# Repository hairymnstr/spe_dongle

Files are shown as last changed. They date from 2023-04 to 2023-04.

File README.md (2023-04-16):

# USB to Single Pair Ethernet Dongle

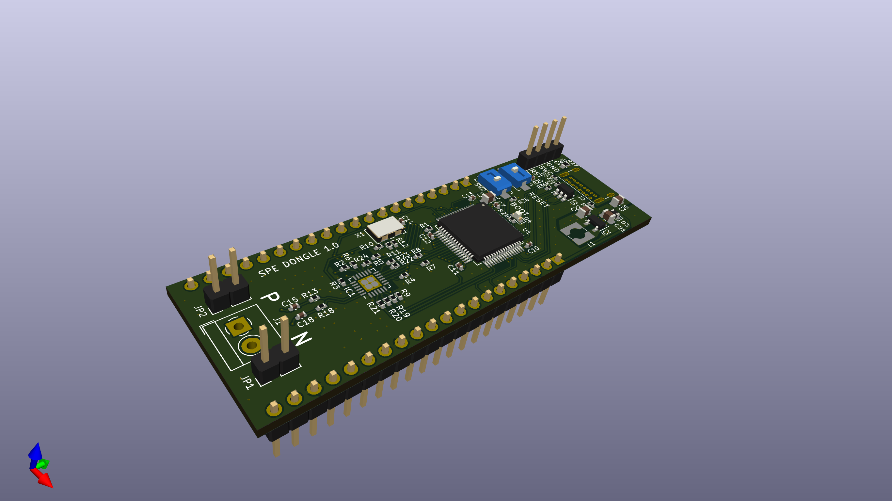
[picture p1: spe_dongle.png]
A screenshot of a CAD render of a small dev board with USB-C and screw terminal connectors


This project is a development board for experimenting with Single Pair Ethernet.
Specifically it has a 10Base-T1S PHY which means it can do short range 10Mbps
comms over a single twisted pair and it is capable of working in a multi-drop
bus without a networks switch.  The board has USB2.0 device only implementation
of the USB-C connector.  The first goal is to make a USB to SPE bridge so that
a Linux host can connect to an SPE network for testing with wireshark etc.

The board also has a number of GPIO broken out to aid in making up devices for
the bus or testing latencies by measuring GPIO toggling etc.

## Design decisions

1. **Why's it using such a low spec processor?**
It's the best I could find in stock.  Chip shortages.  I'd prefer to use
the STM32F407 perhaps, although the smallest pinout for that part is 100 pins
where I only need 64.

2. **Why don't you just buy the USB eval board from Microchip?**
You're right, there is a ready made USB eval board for the LAN867x, but it's
more expensive than this board even making small quantities AND I can't buy it
at the moment.

3. **Will it be the perfect solution then?**
No.  It's going to be okay for testing but the performance is probably going
to be poor.  Apart from anything else it's only Full Speed USB (12Mbps) which
has a 1kHz polling loop meaning you can get 1ms latency on transfers.  Probably
the best option for most applications would be an SPE enabled switch so you can
hook in a real network interface.  There are advantages to being directly connected
to the segment you're investigating for testing though.

## Project status

PCBs are on order.

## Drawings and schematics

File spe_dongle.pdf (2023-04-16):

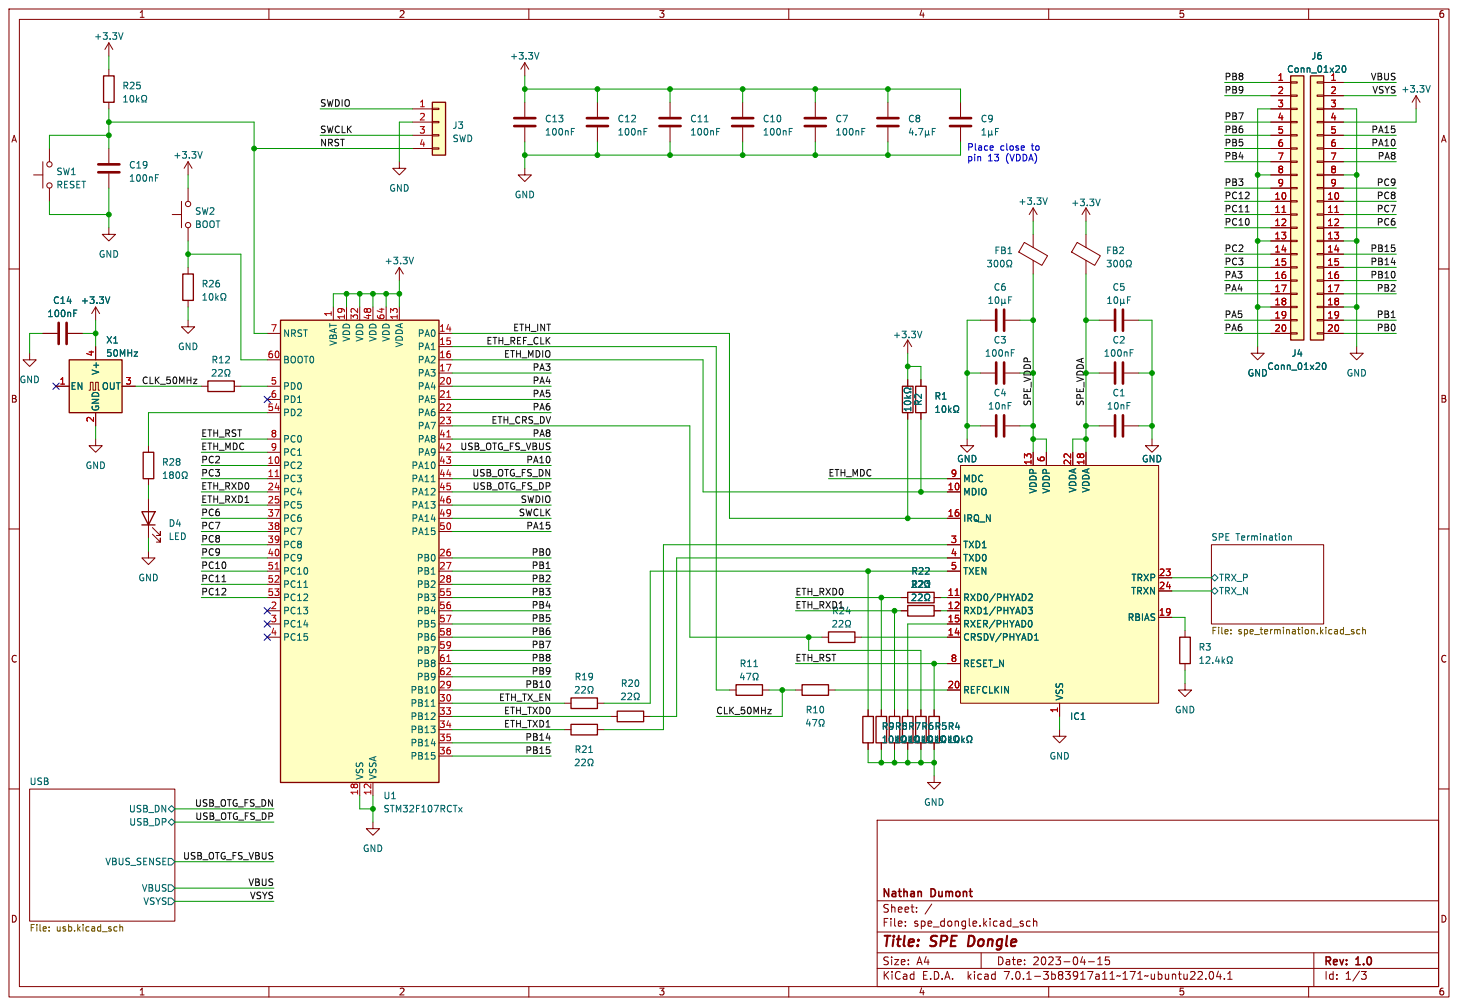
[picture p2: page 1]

1 PC2 10 PC3 11 VSSA 12 VDDA 13 PA0 14 PA1 15 PA2 16 PA3 17 VSS 18 VDD 19 PC13 2 PA4 20 PA5 21 PA6 22 PA7 23 PC4 24 PC5 25 PB0 26 PB1 27 PB2 28 PB10 29 PC14 3 PB11 30 VDD 32 PB12 33 PB13 34 PB14 35 PB15 36 PC6 37 PC7 38 PC8 39 PC15 4 PC9 40 PA8 41 PA9 42 PA10 43 PA11 44 PA12 45 PA13 46 VDD 48 PA14 49 PD0 5 PA15 50 PC10 51 PC11 52 PC12 53 PD2 54 PB3 55 PB4 56 PB5 57 PB6 58 PB7 59 PD1 6 BOOT0 60 PB8 61 PB9 62 VDD 64 NRST 7 PC0 8 PC1 9 U1STM32F107RCTx

1 MDIO 10 RXD0/PHYAD2 11 RXD1/PHYAD3 12 VDDP 13 CRSDV/PHYAD1 14 RXER/PHYAD0 15

Id: 1/3 Title: SPE Dongle

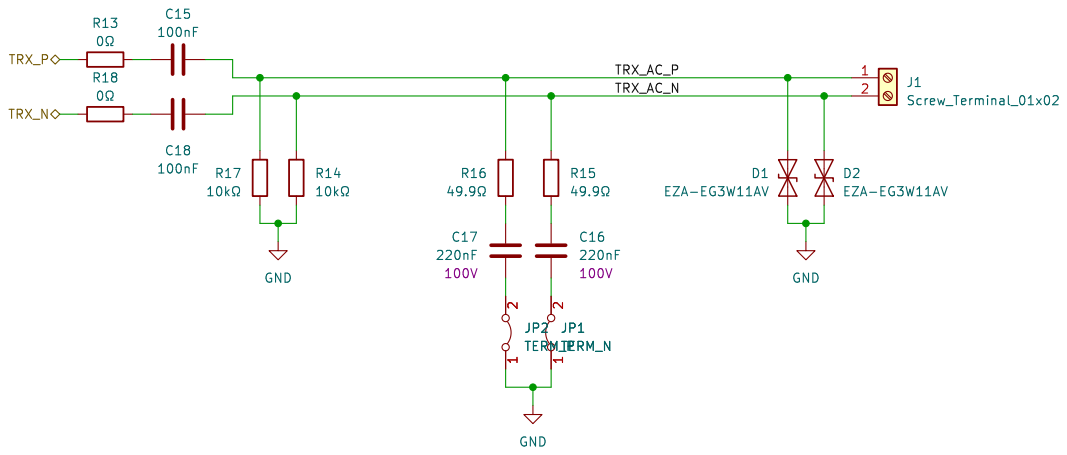
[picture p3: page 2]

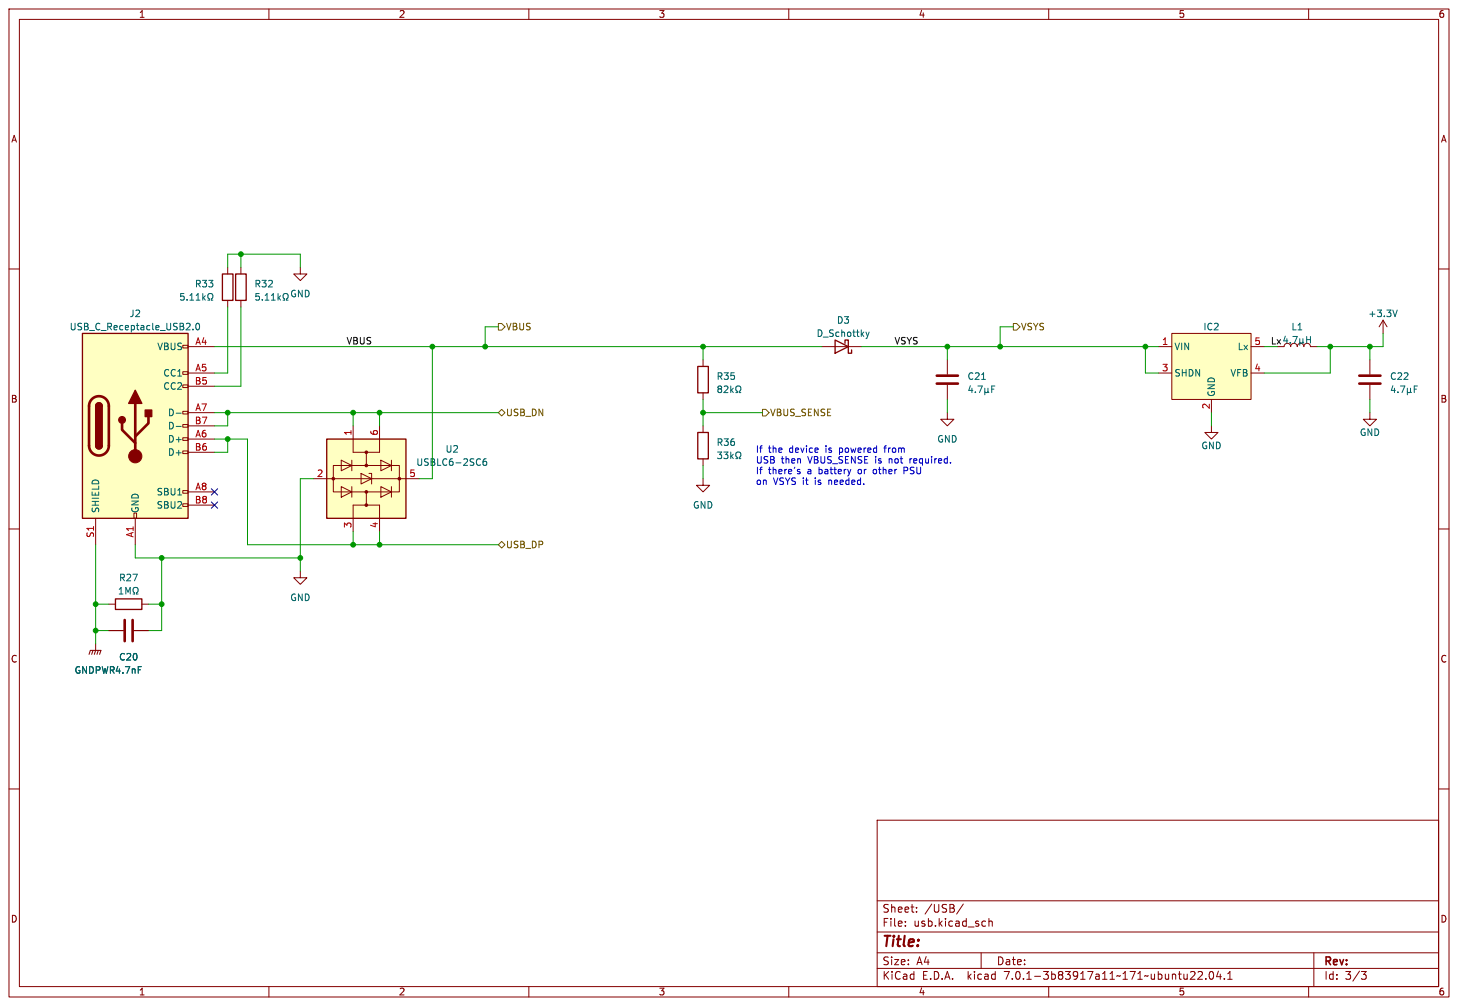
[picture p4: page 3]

If the device is powered from
USB then VBUS_SENSE is not required.
If there's a battery or other PSU

on VSYS it is needed. C20 GNDPWR4.7nF

Id: 3/3 Title: File: usb.kicad_sch Sheet: /USB/

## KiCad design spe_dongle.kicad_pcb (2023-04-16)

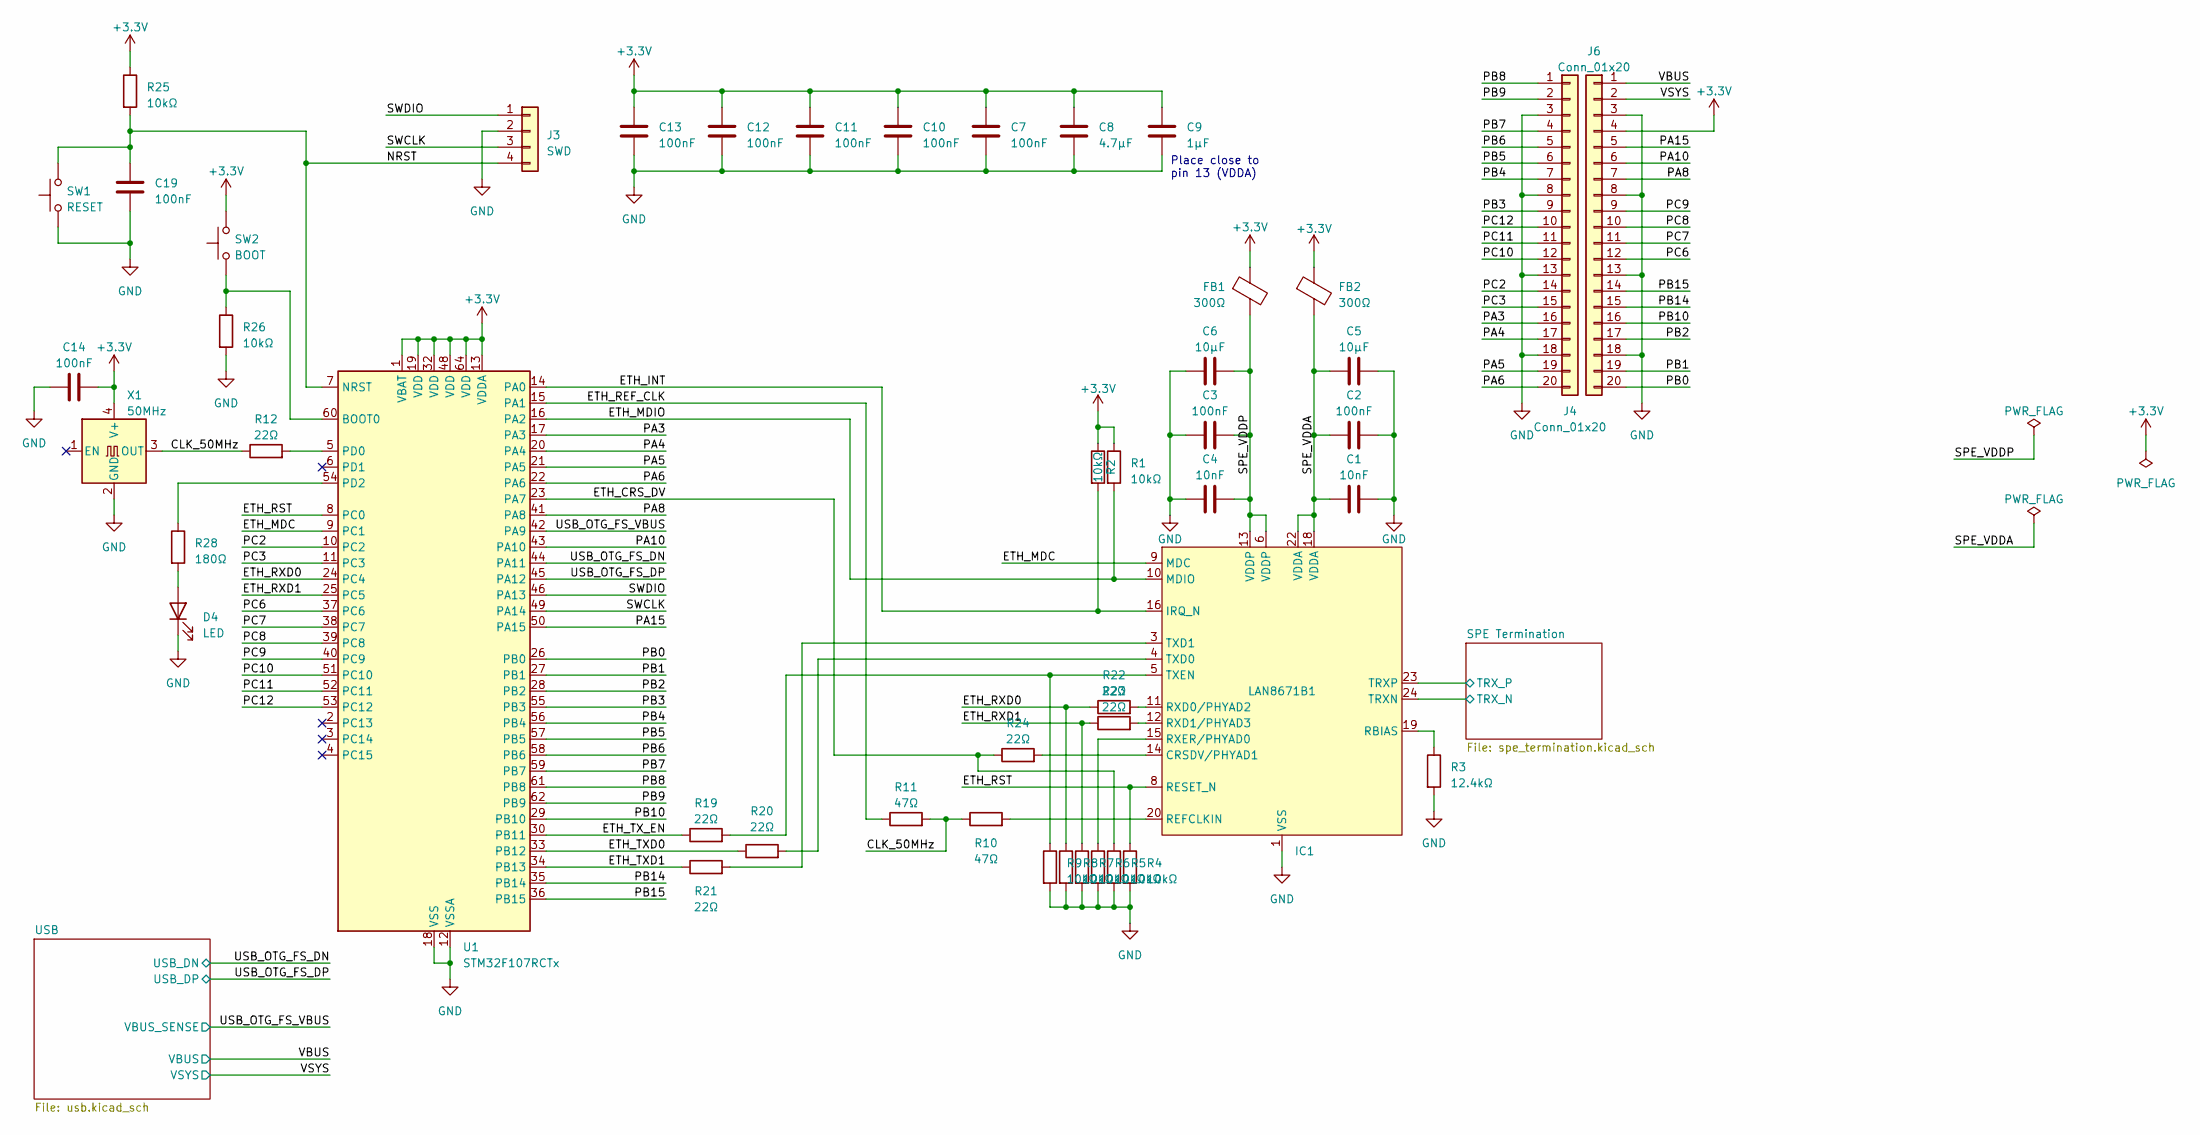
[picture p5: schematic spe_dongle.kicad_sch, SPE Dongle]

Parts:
C1, C4: 10nF; C_0402_1005Metric
C2, C3, C7, C10, C11, C12, C13, C14, C19: 100nF; C_0402_1005Metric
C5, C6: 10µF; C_0603_1608Metric; Farnell 1735528
C8: 4.7µF; C_0805_2012Metric
C9: 1µF; C_0603_1608Metric
D4: LED; LED_0603_1608Metric
FB1, FB2: 300Ω; L_0603_1608Metric
IC1: LAN8671B1; VQFN-24-1EP_4x4mm_P0.5mm_EP2.5x2.5mm_ThermalVias
J3: SWD; PinHeader_1x04_P2.54mm_Vertical
J4, J6: Conn_01x20; PinHeader_1x20_P2.54mm_Vertical
R1, R2, R4, R5, R6, R7, R8, R9, R25, R26: 10kΩ; R_0402_1005Metric
R3: 12.4kΩ; R_0402_1005Metric
R10, R11: 47Ω; R_0402_1005Metric
R12, R19, R20, R21, R22, R23, R24: 22Ω; R_0402_1005Metric
R28: 180Ω; R_0402_1005Metric
SW1: RESET; SW_SPST_EVQPE1
SW2: BOOT; SW_SPST_EVQPE1
U1: STM32F107RCTx; LQFP-64_10x10mm_P0.5mm
X1: 50MHz; Oscillator_SMD_EuroQuartz_XO53-4Pin_5.0x3.2mm; Farnell 1640969

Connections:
+3.3V: C7.1, C8.1, C9.1, C10.1, C11.1, C12.1, C13.1, C14.2, FB1.1, FB2.1, J6.4, R1.1, R2.1, R25.1, SW2.2, U1.1 (VBAT), U1.13 (VDDA), U1.19 (VDD), U1.32 (VDD), U1.48 (VDD), U1.64 (VDD), X1.4 (V+); also elsewhere on the board
/CLK_50MHz: R10.1, R11.2, R12.1, X1.3 (OUT)
/ETH_CRS_DV: R5.1, R24.1, U1.23 (PA7)
/ETH_INT: IC1.16 (IRQ_N), R2.2, U1.14 (PA0)
/ETH_MDC: IC1.9 (MDC), U1.9 (PC1)
/ETH_MDIO: IC1.10 (MDIO), R1.2, U1.16 (PA2)
/ETH_REF_CLK: R11.1, U1.15 (PA1)
/ETH_RST: IC1.8 (RESET_N), R4.1, U1.8 (PC0)
/ETH_RXD0: R8.1, R22.1, U1.24 (PC4)
/ETH_RXD1: R7.1, R23.1, U1.25 (PC5)
/ETH_TXD0: R20.1, U1.33 (PB12)
/ETH_TXD1: R21.1, U1.34 (PB13)
/ETH_TX_EN: R19.1, U1.30 (PB11)
/NRST: C19.1, J3.4, R25.2, SW1.2, U1.7 (NRST)
/PA3: J4.16, U1.17 (PA3)
/PA4: J4.17, U1.20 (PA4)
/PA5: J4.19, U1.21 (PA5)
/PA6: J4.20, U1.22 (PA6)
/PA8: J6.7, U1.41 (PA8)
/PA10: J6.6, U1.43 (PA10)
/PA15: J6.5, U1.50 (PA15)
/PB0: J6.20, U1.26 (PB0)
/PB1: J6.19, U1.27 (PB1)
/PB2: J6.17, U1.28 (PB2)
/PB3: J4.9, U1.55 (PB3)
/PB4: J4.7, U1.56 (PB4)
/PB5: J4.6, U1.57 (PB5)
/PB6: J4.5, U1.58 (PB6)
/PB7: J4.4, U1.59 (PB7)
/PB8: J4.1, U1.61 (PB8)
/PB9: J4.2, U1.62 (PB9)
/PB10: J6.16, U1.29 (PB10)
/PB14: J6.15, U1.35 (PB14)
/PB15: J6.14, U1.36 (PB15)
/PC2: J4.14, U1.10 (PC2)
/PC3: J4.15, U1.11 (PC3)
/PC6: J6.12, U1.37 (PC6)
/PC7: J6.11, U1.38 (PC7)
/PC8: J6.10, U1.39 (PC8)
/PC9: J6.9, U1.40 (PC9)
/PC10: J4.12, U1.51 (PC10)
/PC11: J4.11, U1.52 (PC11)
/PC12: J4.10, U1.53 (PC12)
/SPE Termination/TRX_N: IC1.24 (TRXN); also elsewhere on the board
/SPE Termination/TRX_P: IC1.23 (TRXP); also elsewhere on the board
/SPE_VDDA: C1.1, C2.1, C5.1, FB2.2, IC1.18 (VDDA), IC1.22 (VDDA)
/SPE_VDDP: C3.2, C4.2, C6.2, FB1.2, IC1.6 (VDDP), IC1.13 (VDDP)
/SWCLK: J3.3, U1.49 (PA14)
/SWDIO: J3.1, U1.46 (PA13)
/USB_OTG_FS_DN: U1.44 (PA11); also elsewhere on the board
/USB_OTG_FS_DP: U1.45 (PA12); also elsewhere on the board
/USB_OTG_FS_VBUS: U1.42 (PA9); also elsewhere on the board
/VBUS: J6.1; also elsewhere on the board
/VSYS: J6.2; also elsewhere on the board
GND: C1.2, C2.2, C3.1, C4.1, C5.2, C6.1, C7.2, C8.2, C9.2, C10.2, C11.2, C12.2, C13.2, C14.1, C19.2, D4.1 (K), IC1.1 (VSS), IC1.25 (VSS), J3.2, J4.3, J4.8, J4.13, J4.18, J6.3, J6.8, J6.13, J6.18, R3.2, R4.2, R5.2, R6.2, R7.2, R8.2, R9.2, R26.2, SW1.1, U1.12 (VSSA), U1.18 (VSS), U1.31 (VSS), U1.47 (VSS), U1.63 (VSS), X1.2 (GND); also elsewhere on the board
unnamed: D4.2 (A), R28.2
unnamed: IC1.14 (CRSDV/PHYAD1), R24.2
unnamed: IC1.19 (RBIAS), R3.1
unnamed: IC1.20 (REFCLKIN), R10.2
unnamed: IC1.11 (RXD0/PHYAD2), R22.2
unnamed: IC1.12 (RXD1/PHYAD3), R23.2
unnamed: IC1.15 (RXER/PHYAD0), R6.1
unnamed: IC1.4 (TXD0), R20.2
unnamed: IC1.3 (TXD1), R21.2
unnamed: IC1.5 (TXEN), R9.1, R19.2
unnamed: R26.1, SW2.1, U1.60 (BOOT0)
unnamed: R12.2, U1.5 (PD0)
unnamed: R28.1, U1.54 (PD2)

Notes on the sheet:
Place close to pin 13 (VDDA)

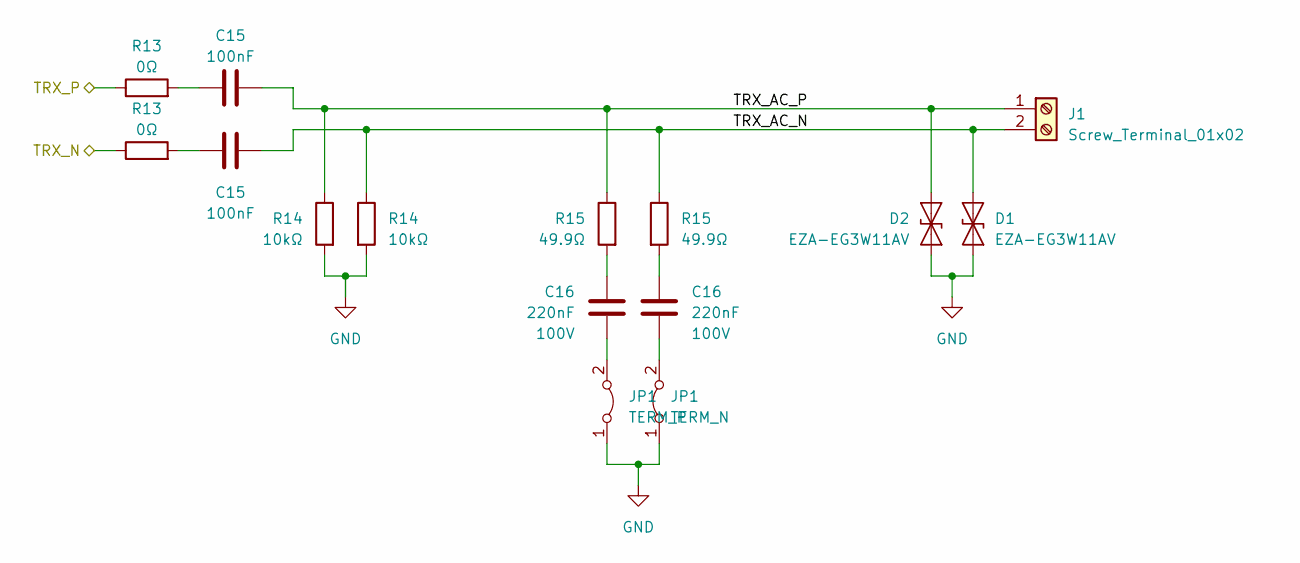
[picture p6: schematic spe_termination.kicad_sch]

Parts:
C15: 100nF; C_0402_1005Metric
C16: 220nF; C_0805_2012Metric; Voltage 100V; Farnell 2494267
D1, D2: EZA-EG3W11AV; D_0603_1608Metric; Farnell 3219333
J1: Screw_Terminal_01x02; TerminalBlock_4Ucon_1x02_P3.50mm_Horizontal
JP1: TERM_P; PinHeader_1x02_P2.54mm_Vertical
R13: 0Ω; R_0402_1005Metric
R14: 10kΩ; R_1206_3216Metric; Farnell 3127861
R15: 49.9Ω; R_1206_3216Metric; Farnell 2095158

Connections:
/SPE Termination/TRX_P: R13.1; also elsewhere on the board
GND: D1.1 (A1), D2.1 (A1), JP1.1 (A), R14.2; also elsewhere on the board
unnamed: C15.1, R13.2
unnamed: C16.1, R15.2
unnamed: C16.2, JP1.2 (B)

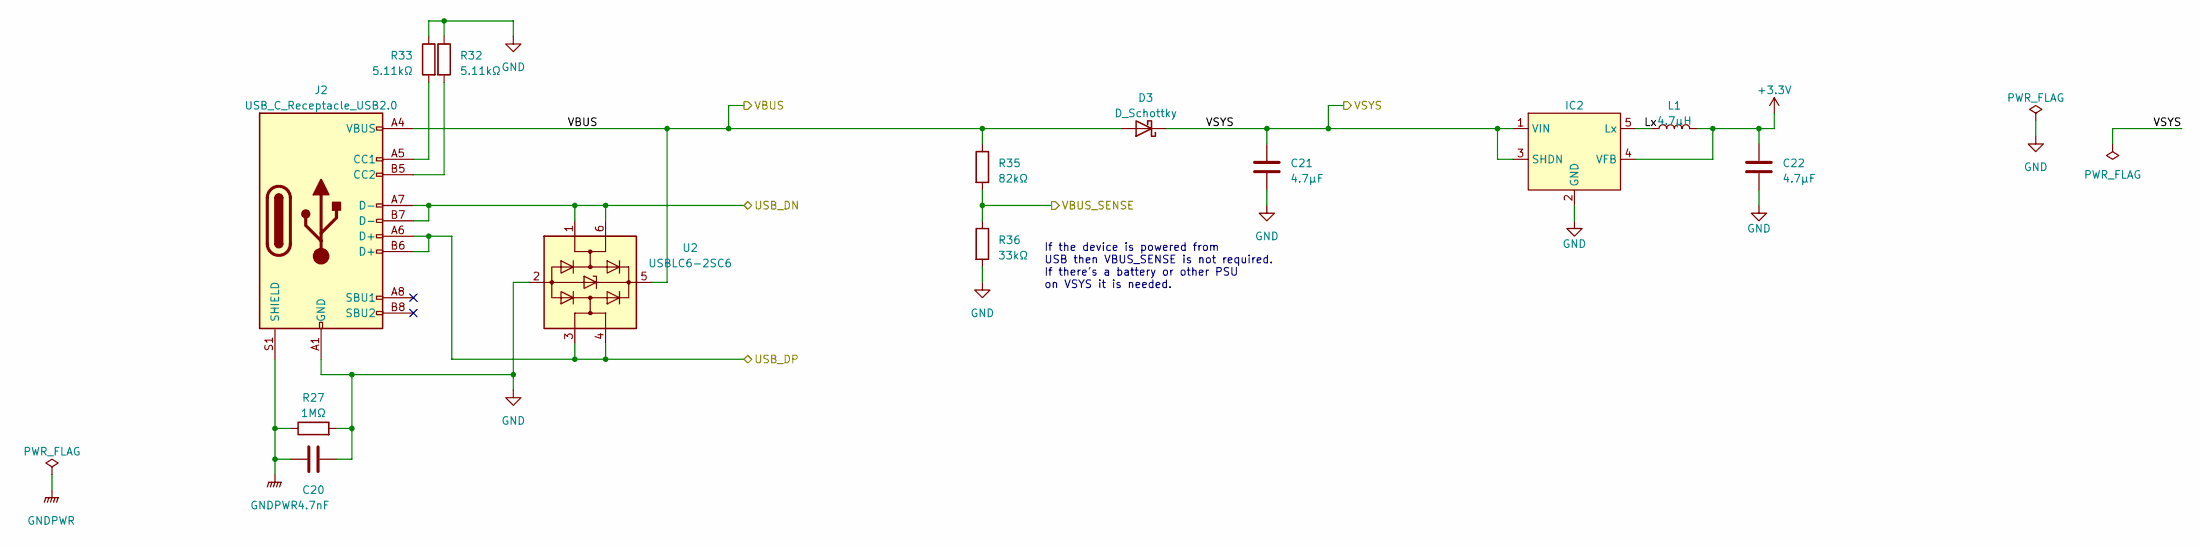
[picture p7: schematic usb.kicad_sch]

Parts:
C20: 4.7nF; C_0805_2012Metric
C21, C22: 4.7µF; C_0805_2012Metric
D3: D_Schottky; D_0603_1608Metric
IC2: TSOT-23-5
J2: USB_C_Receptacle_USB2.0; USB_C_Receptacle_GCT_USB4085
L1: 4.7µH; L_Wuerth_WE-TPC-3816
R27: 1MΩ; R_0603_1608Metric
R32, R33: 5.11kΩ; R_0402_1005Metric
R35: 82kΩ; R_0402_1005Metric
R36: 33kΩ; R_0402_1005Metric
U2: USBLC6-2SC6; SOT-23-6

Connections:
+3.3V: C22.1, IC2.4 (VFB), L1.2; also elsewhere on the board
/USB/Lx: IC2.5 (Lx), L1.1
/USB_OTG_FS_DN: J2.A7 (D-), J2.B7 (D-), U2.1 (I/O1), U2.6 (I/O1); also elsewhere on the board
/USB_OTG_FS_DP: J2.A6 (D+), J2.B6 (D+), U2.3 (I/O2), U2.4 (I/O2); also elsewhere on the board
/USB_OTG_FS_VBUS: R35.2, R36.1; also elsewhere on the board
/VBUS: D3.2 (A), J2.A4 (VBUS), J2.A9 (VBUS), J2.B4 (VBUS), J2.B9 (VBUS), R35.1, U2.5 (VBUS); also elsewhere on the board
/VSYS: C21.1, D3.1 (K), IC2.1 (VIN), IC2.3 (SHDN); also elsewhere on the board
GND: C20.2, C21.2, C22.2, IC2.2 (GND), J2.A1 (GND), J2.A12 (GND), J2.B1 (GND), J2.B12 (GND), R27.2, R32.1, R33.1, R36.2, U2.2 (GND); also elsewhere on the board
GNDPWR: C20.1, J2.S1 (SHIELD), R27.1
unnamed: J2.A5 (CC1), R33.2
unnamed: J2.B5 (CC2), R32.2

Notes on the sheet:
If the device is powered from USB then VBUS_SENSE is not required. If there's a battery or other PSU on VSYS it is needed.

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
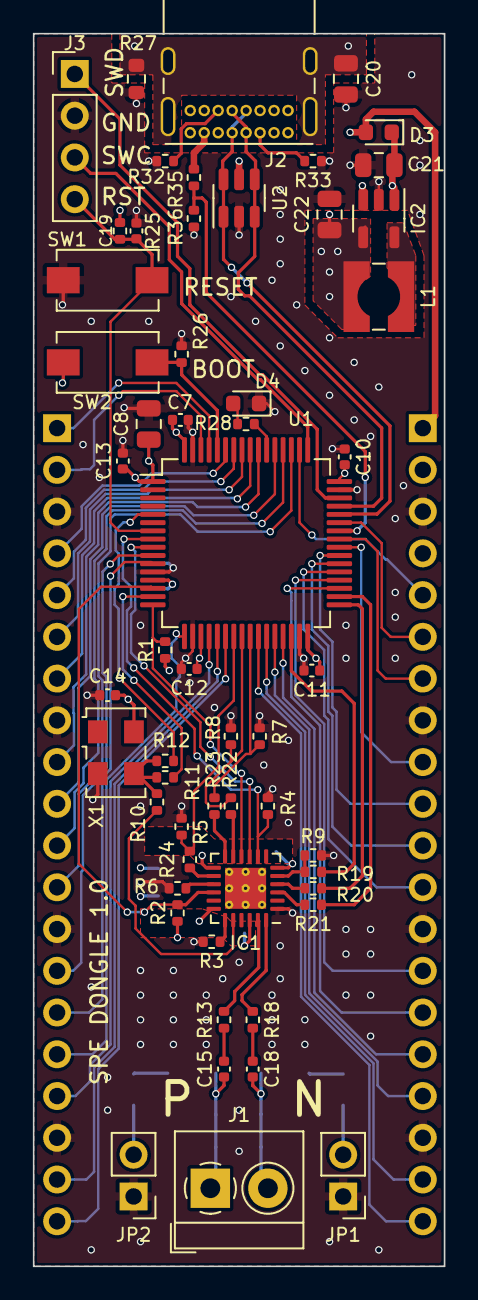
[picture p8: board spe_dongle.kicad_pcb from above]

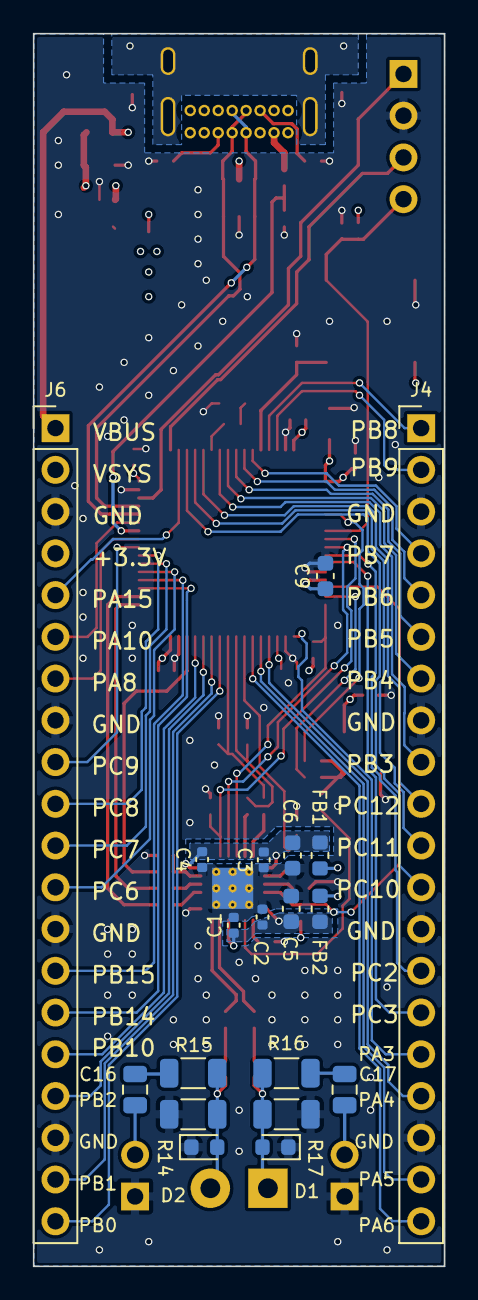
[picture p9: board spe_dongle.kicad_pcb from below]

Board: 4 copper layers, 25.0 x 75.0 mm, 75 parts (19 on the bottom side), 80 nets.

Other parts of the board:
C17: 220nF; C_0805_2012Metric
C18: 100nF; C_0402_1005Metric
JP2: TERM_P; PinHeader_1x02_P2.54mm_Vertical
R16: 49.9Ω; R_1206_3216Metric
R17: 10kΩ; R_1206_3216Metric
R18: 0Ω; R_0402_1005Metric

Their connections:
/SPE Termination/TRX_N: R18.1; also elsewhere on the board
GND: JP2.1 (A), R17.2; also elsewhere on the board
unnamed: C17.1, R16.2
unnamed: C18.1, R18.2
unnamed: C17.2, JP2.2 (B)
